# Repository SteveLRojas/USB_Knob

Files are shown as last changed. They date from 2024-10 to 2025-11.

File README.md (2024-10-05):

# USB_Knob
A USB knob that can scroll, pan, adjust the volume, and more. Uses the CH552 USB microcontroller.

## What does it do?
This device is a computer peripheral, it can scroll, pan (scroll horizontally), and adjust the volume. It also has simple media controls such as play/pause, next, and prev.  

## How does it work?
The device has 3 buttons: left, center, and right. These 3 buttons are used to set the "mode" of the device, and when they are held down they act as function modifiers. The device also has a knob which has a fourth button, and is the most frequently used control on the device. Three indicator LEDs indicate the current "mode" setting of the device.  

## Device features
### Scroll mode
- Press the left button to enter scroll mode.  
- The knob button functions as the middle mouse button.  
- While the left button is released spinning the knob scrolls vertically (like a mouse wheel).  
- While the left button is pressed spinning the knob adjusts the scrolling speed (the speed range is 1 to 10).  
### Pan mode
- Press the center button to enter pan mode.  
- If the mouse wiggler feature is enabled (option set at compile time) the knob button toggles the mouse wiggler on/off. The mouse wiggler only acts when the knob is in pan mode, but the on/off state is maintained even when the device is in a different mode.  
- If the mouse wiggler feature is not enabled then the knob button functions as the middle mouse button.  
- While the center button is released spinning the knob scrolls horizontally.  
- While the center button is pressed spinning the knob adjusts the scrolling (pan) speed (the range is 1 to 10).  
### Volume mode
- Press the right button to enter volume mode.  
- While the right button is released the knob button acts as a mute button.  
- While the right button is pressed the knob button acts as a play/pause button.  
- While the right button is released spinning the knob adjusts the volume.  
- While the right button is pressed spinning the knob functions as media next/prev buttons.

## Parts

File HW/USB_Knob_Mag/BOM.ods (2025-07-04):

Part | #Needed | #Owned | Satisfied? | Location
CH552T | 1 | 6 | TRUE | Project box
AS5600-ASOM | 1 | 20 | TRUE | Project box
Crystal 24MHz 3225 | 1 | 0 | FALSE | Crystal Box
LED Orange 0805 | 3 | 1000 | TRUE | Project box
USB C Socket | 1 | 10 | TRUE | Connector box
Pin Header 1X3 right angle | 1 | 10 | TRUE | Connector box
Pin Header 1X2 right angle | 1 | 10 | TRUE | Connector box
Capacitor 1u 0805 | 1 | 200 | TRUE | Box 7
Capacitor 0.1u 0805 | 3 | 100 | TRUE | Project box
Capacitor 10u 1206 | 1 | 50 | TRUE | Project box
Capacitor 20p 0805 | 2 | 0 | FALSE
Push Button SMD | 3 | 20 | TRUE | Project box
Resistor 5.1K 0805 | 2 | 1000 | TRUE | Project box
Resistor 1K 0805 | 8 | 1000 | TRUE | Box 8
Resistor 10K 0805 | 1 | 1000 | TRUE | Box 8

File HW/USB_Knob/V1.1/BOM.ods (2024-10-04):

Part | #Needed | #Owned | Satisfied? | Location
CH552T | 1 | 12 | TRUE | Project box
74LVC1G17 | 2 | 14 | TRUE | Project box
Crystal 24MHz 3225 | 1 | 0 | FALSE
LED Orange 0805 | 3 | 1000 | TRUE | Project box
USB Mini C Socket | 1 | 10 | TRUE | Connector box
Rotary Encoder | 1 | 10 | TRUE | Project box
Pin Header 1X3 | 1 | 10 | TRUE | Connector box
Pin Header 1X2 | 1 | 10 | TRUE | Connector box
Capacitor 0.01u 0805 | 2 | 100 | TRUE | Project box
Capacitor 0.1u 0805 | 4 | 100 | TRUE | Project box
Capacitor 10u 1206 | 1 | 10 | TRUE | Project box
Capacitor 20p 0805 | 2 | 0 | FALSE
Push Button SMD | 3 | 50 | TRUE | Project box
Resistor 5.1K 0805 | 2 | 1000 | TRUE | Project box
Resistor 1K 0805 | 9 | 1000 | TRUE | Box 8
Resistor 10K 0805 | 3 | 1000 | TRUE | Box 8

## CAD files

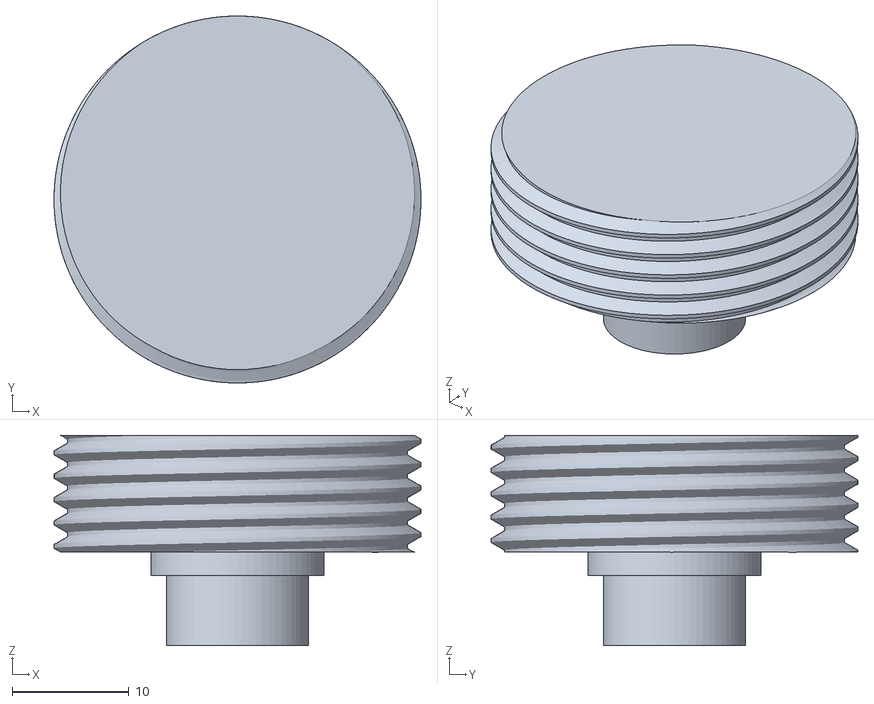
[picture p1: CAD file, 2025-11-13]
3d_models/mag/USB_Knob_Mag_Holder.stl
31.4 x 31.4 x 18.0

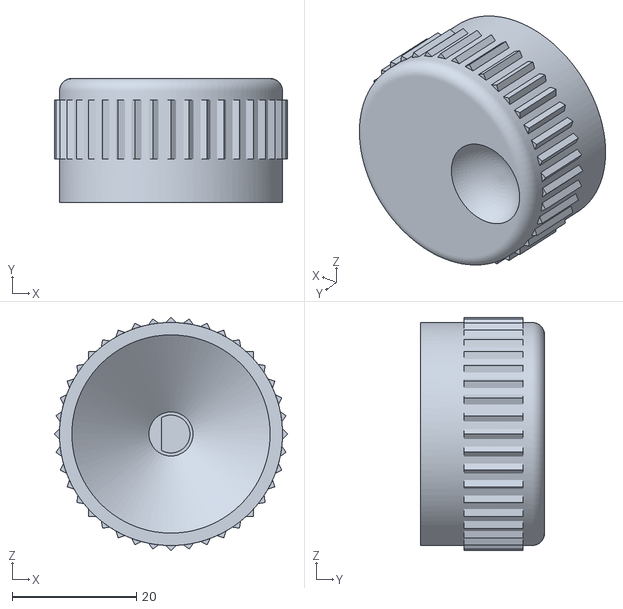
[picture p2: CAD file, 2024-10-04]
3d_models/USB_knob_the_v1.1.stl
37.5 x 20.0 x 37.5

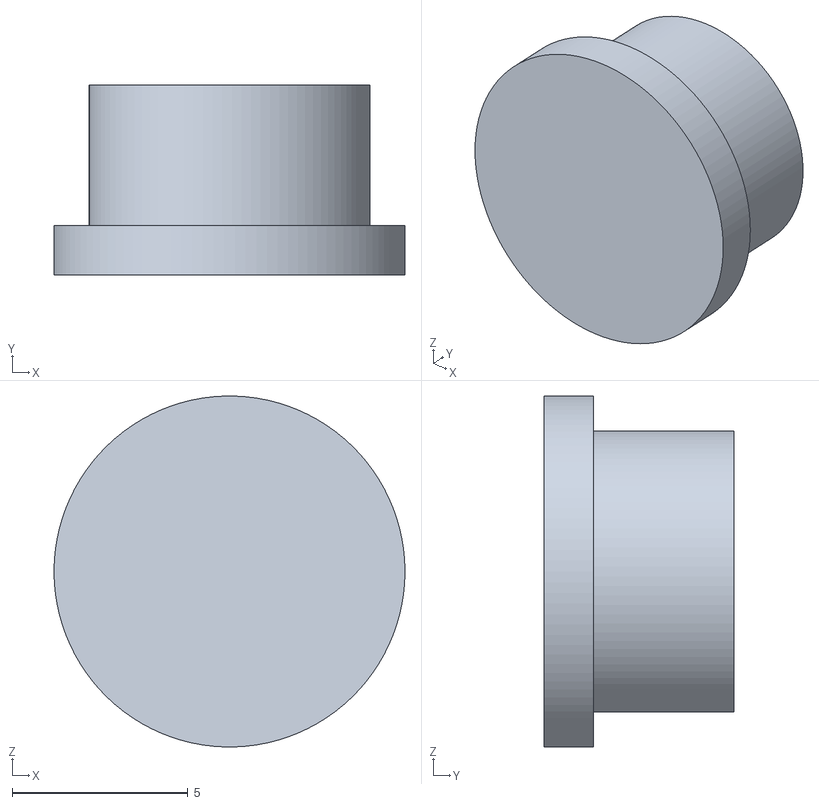
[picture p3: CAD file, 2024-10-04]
3d_models/knob_button_v1.1.stl
10.0 x 5.40 x 10.00

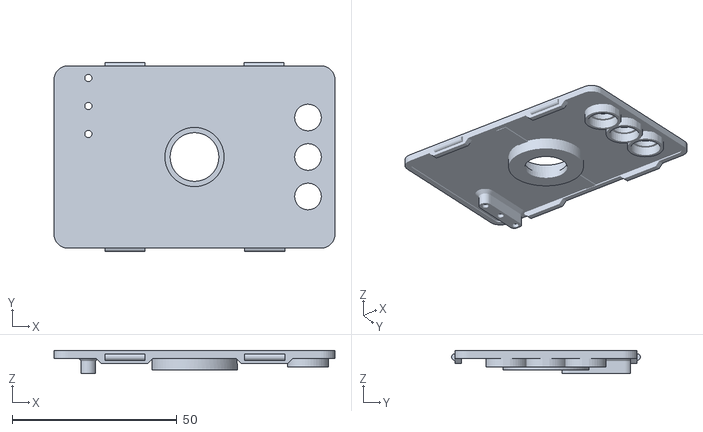
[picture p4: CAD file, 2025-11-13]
3d_models/mag/USB_Knob_Cap_Mag.stl
85.4 x 57.4 x 7.00

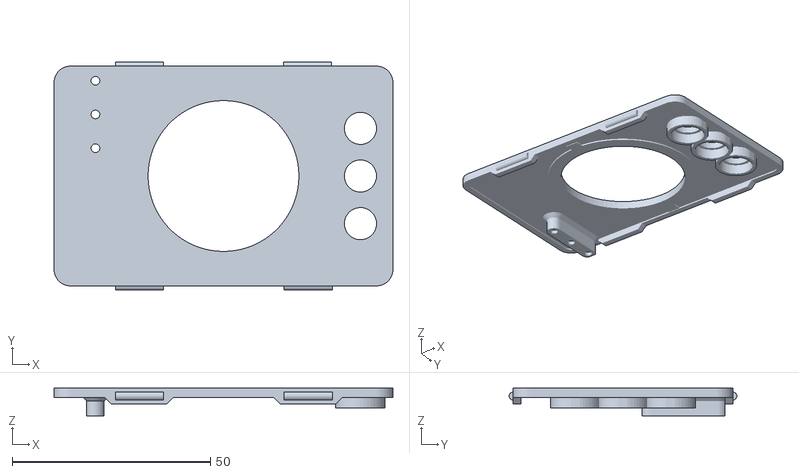
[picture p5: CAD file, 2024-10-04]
3d_models/knob_cap.stl
85.4 x 57.4 x 7.00

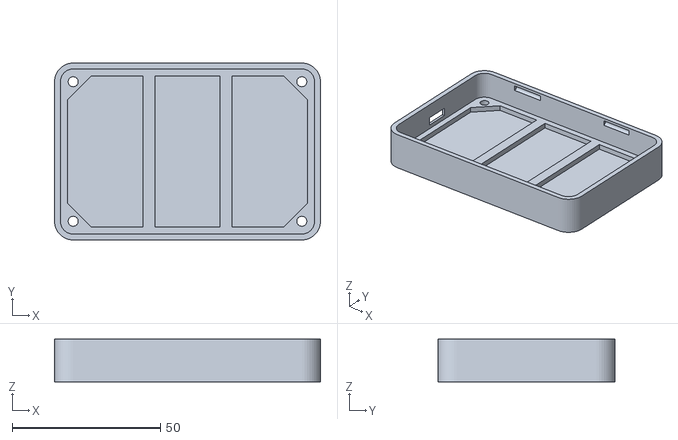
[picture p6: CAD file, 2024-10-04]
3d_models/knob_box.stl
89.6 x 59.6 x 14.4

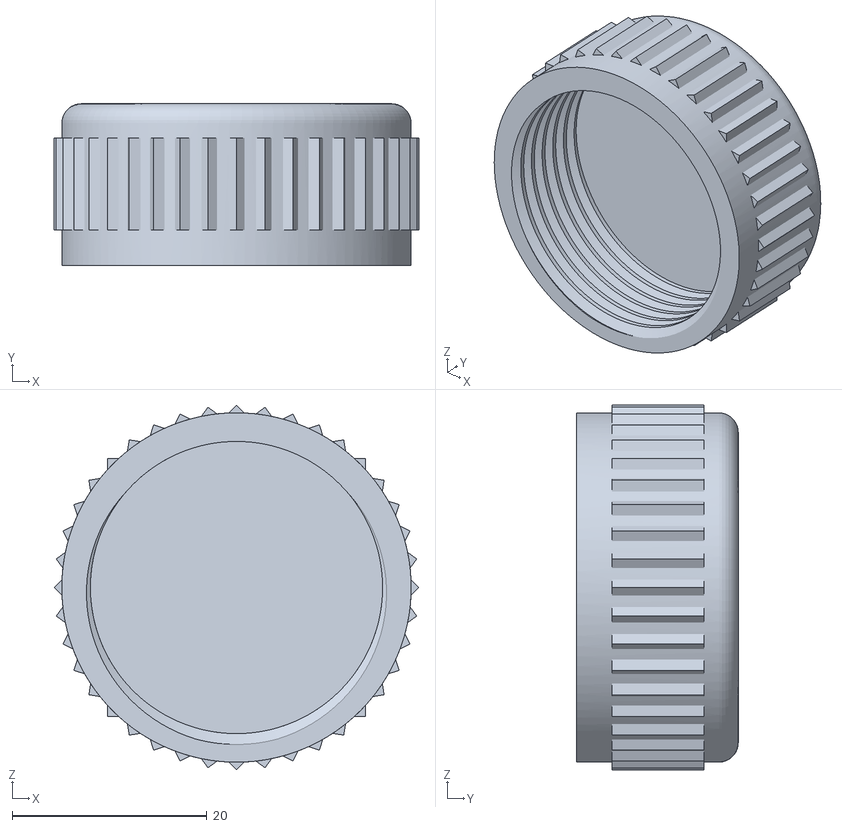
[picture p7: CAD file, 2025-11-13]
3d_models/mag/USB_Knob_Mag_Screw.stl
37.5 x 16.6 x 37.5

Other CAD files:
3d_models/USB_Knob_Box v5.f3d
3d_models/USB_knob_the v4.f3d
3d_models/button v2.f3d
3d_models/mag/USB_Knob_Box_Mag v5.f3d
3d_models/mag/USB_Knob_Mag_Holder v4.f3d
3d_models/mag/USB_Knob_Mag_screw v3.f3d

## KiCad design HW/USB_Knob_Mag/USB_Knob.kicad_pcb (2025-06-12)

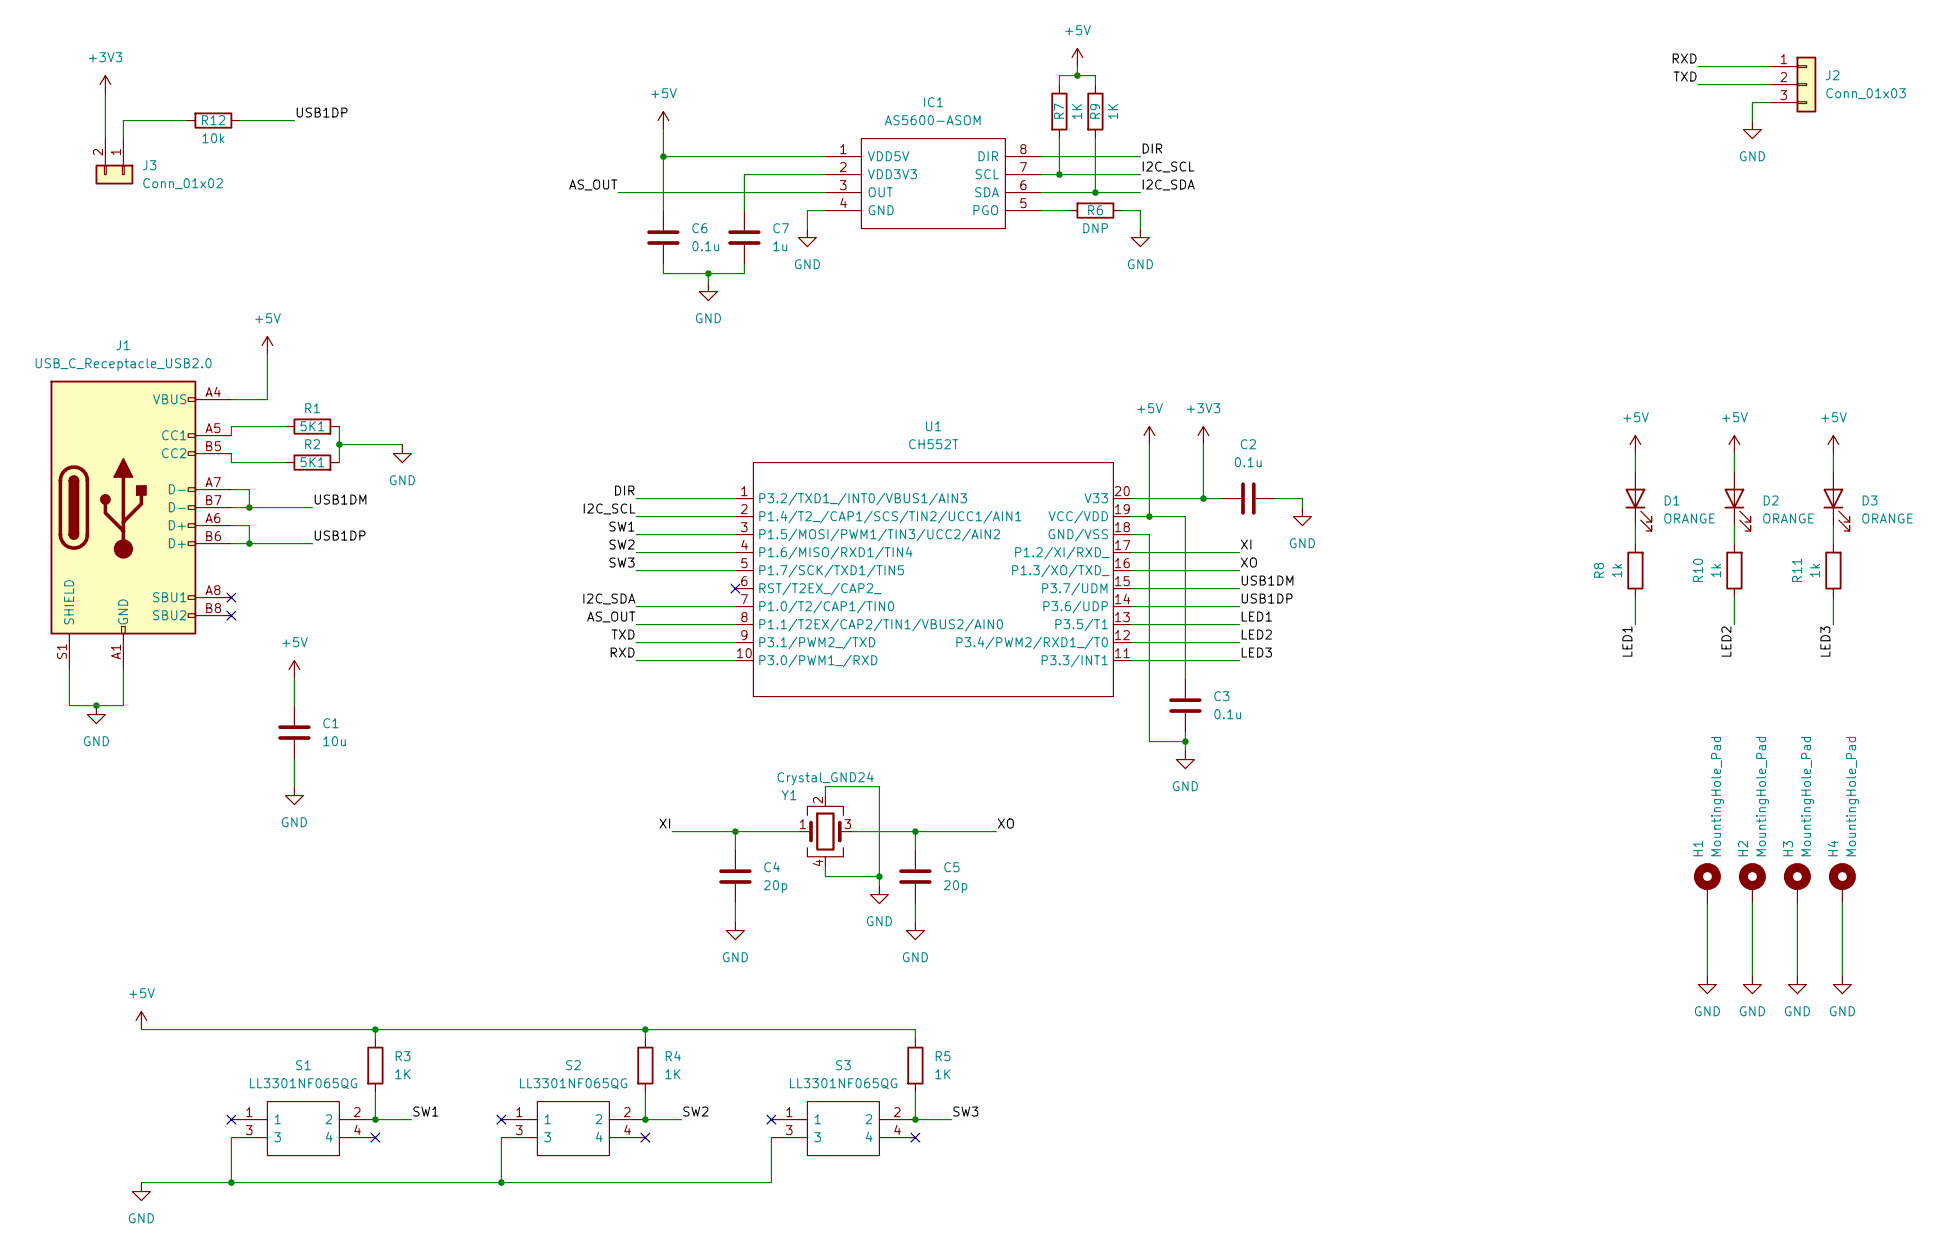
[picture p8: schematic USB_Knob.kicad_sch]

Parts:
C1: 10u; C_1206_3216Metric
C2, C3, C6: 0.1u; C_0805_2012Metric
C4, C5: 20p; C_0805_2012Metric
C7: 1u; C_0805_2012Metric
D1, D2, D3: ORANGE; LED_0805_2012Metric
H1, H2, H3, H4: MountingHole_Pad; MountingHole_3.2mm_M3_Pad
IC1: AS5600-ASOM; SOIC127P600X175-8N; Mouser Part Number 985-AS5600-ASOM
J1: USB_C_Receptacle_USB2.0; USB_C_Receptacle_HRO_TYPE-C-31-M-12
J2: Conn_01x03; PinHeader_1x03_P2.54mm_Horizontal
J3: Conn_01x02; PinHeader_1x02_P2.54mm_Horizontal
R1, R2: 5K1; R_0805_2012Metric
R3, R4, R5, R7, R9: 1K; R_0805_2012Metric
R6: DNP; R_0805_2012Metric
R8, R10, R11: 1k; R_0805_2012Metric
R12: 10k; R_0805_2012Metric
S1, S2, S3: LL3301NF065QG; Mouser Part Number 612-LL3301NF065QG
U1: CH552T; TSSOP-20_4.4x6.5mm_P0.65mm
Y1: Crystal_GND24; Crystal_SMD_3225-4Pin_3.2x2.5mm

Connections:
+3V3: C2.1, J3.2, U1.20 (V33)
+5V: C1.1, C3.2, C6.2, D1.2 (A), D2.2 (A), D3.2 (A), IC1.1 (VDD5V), J1.A4 (VBUS), J1.A9 (VBUS), J1.B4 (VBUS), J1.B9 (VBUS), R3.1, R4.1, R5.1, R7.1, R9.1, U1.19 (VCC/VDD)
/AS_OUT: IC1.3 (OUT), U1.8 (P1.1/T2EX/CAP2/TIN1/VBUS2/AIN0)
/DIR: IC1.8 (DIR), U1.1 (P3.2/TXD1_/INT0/VBUS1/AIN3)
/I2C_SCL: IC1.7 (SCL), R7.2, U1.2 (P1.4/T2_/CAP1/SCS/TIN2/UCC1/AIN1)
/I2C_SDA: IC1.6 (SDA), R9.2, U1.7 (P1.0/T2/CAP1/TIN0)
/LED1: R8.1, U1.13 (P3.5/T1)
/LED2: R10.1, U1.12 (P3.4/PWM2/RXD1_/T0)
/LED3: R11.1, U1.11 (P3.3/INT1)
/RXD: J2.1, U1.10 (P3.0/PWM1_/RXD)
/SW1: R3.2, S1.2, U1.3 (P1.5/MOSI/PWM1/TIN3/UCC2/AIN2)
/SW2: R4.2, S2.2, U1.4 (P1.6/MISO/RXD1/TIN4)
/SW3: R5.2, S3.2, U1.5 (P1.7/SCK/TXD1/TIN5)
/TXD: J2.2, U1.9 (P3.1/PWM2_/TXD)
/USB1DM: J1.A7 (D-), J1.B7 (D-), U1.15 (P3.7/UDM)
/USB1DP: J1.A6 (D+), J1.B6 (D+), R12.1, U1.14 (P3.6/UDP)
/XI: C4.2, U1.17 (P1.2/XI/RXD_), Y1.1
/XO: C5.2, U1.16 (P1.3/XO/TXD_), Y1.3
GND: C1.2, C2.2, C3.1, C4.1, C5.1, C6.1, C7.1, H1.1, H2.1, H3.1, H4.1, IC1.4 (GND), J1.A1 (GND), J1.A12 (GND), J1.B1 (GND), J1.B12 (GND), J1.S1 (SHIELD), J2.3, R1.2, R2.2, R6.1, S1.3, S2.3, S3.3, U1.18 (GND/VSS), Y1.2, Y1.4
unnamed: C7.2, IC1.2 (VDD3V3)
unnamed: D1.1 (K), R8.2
unnamed: D2.1 (K), R10.2
unnamed: D3.1 (K), R11.2
unnamed: IC1.5 (PGO), R6.2
unnamed: J1.A5 (CC1), R1.1
unnamed: J1.B5 (CC2), R2.1
unnamed: J3.1, R12.2

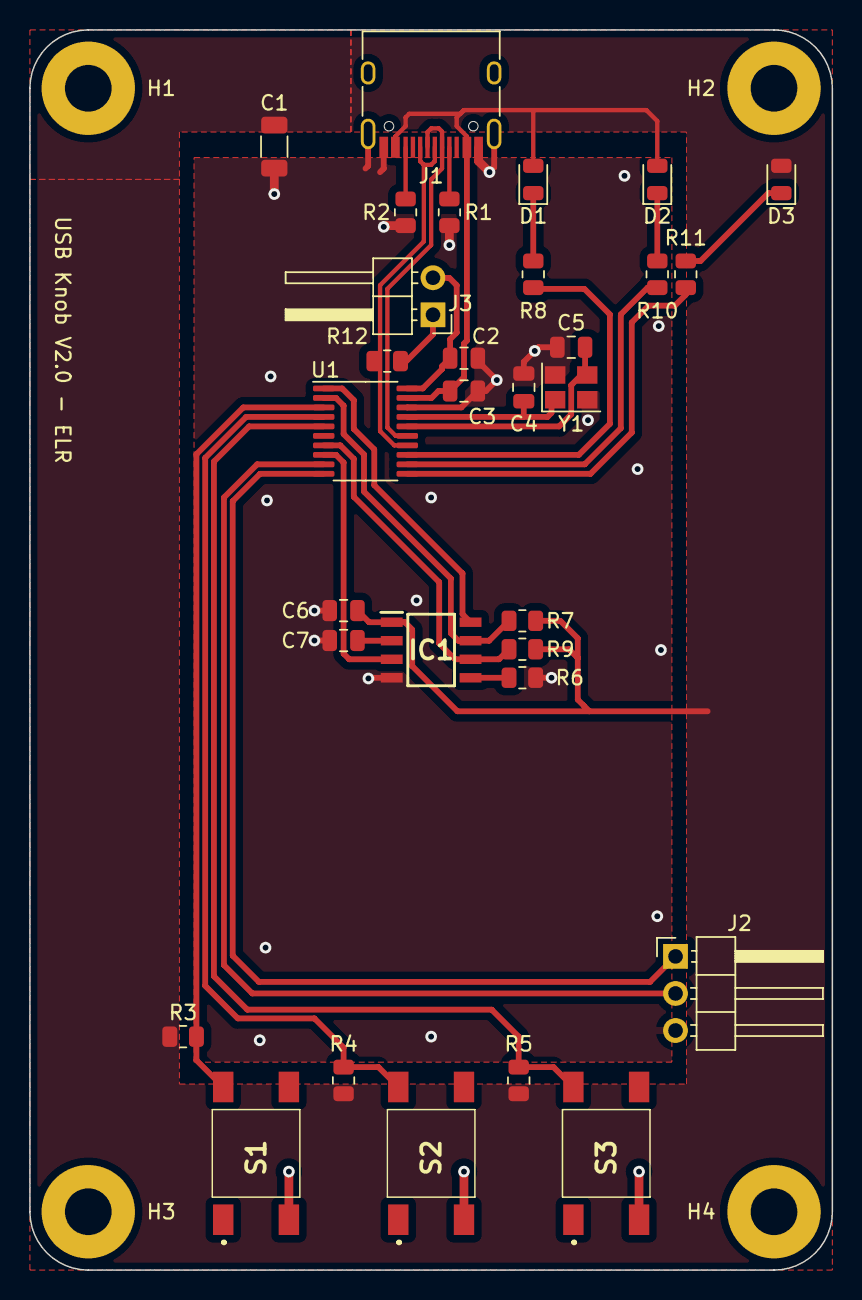
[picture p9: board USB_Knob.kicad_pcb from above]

Board: 2 copper layers, 55.0 x 85.0 mm, 35 parts (0 on the bottom side), 27 nets.

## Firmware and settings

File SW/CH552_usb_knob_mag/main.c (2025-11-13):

#include "CH552.H"
#include "CH552_RCC.h"
#include "CH552_GPIO.h"
#include "CH552_UART.h"
#include "CH552_TIMER.h"
#include "CH552_HID_CC_PAN_MOUSE.h"
#include "CH552_I2C.h"
#include "CH552_AS5600.h"
#include "pseudo_random.h"

#define BAUD_RATE		125000ul
#define ENABLE_DEBUG	0
#define ENABLE_WIGGLER	1
#define SPEED_STEPS		16
#define FINE_SHIFT		7
#define COARSE_HYSTERESIS	128
#define FINE_HYSTERESIS		4
#define DEBOUNCE_SAMPLES	8

//Pins:
// I2C_SDA = P10
// AS_OUT = P11
// I2C_SCL = P14
// SW1 = P15
// SW2 = P16
// SW3 = P17
// RXD = P30
// TXD = P31
// DIR = P32
// LED3 = P33
// LED2 = P34
// LED1 = P35
// UDP = P36
// UDM = P37

#define KNOB_MODE_SCROLL 0
#define KNOB_MODE_PAN 1
#define KNOB_MODE_VOLUME 2

#if ENABLE_DEBUG
char code test_string[] = "Unicorn\n";
char code pos_raw_str[] = "knob_pos_raw: ";
char code pos_coarse_str[] = "knob_pos_coarse: ";
char code pos_fine_str[] = "knob_pos_fine: ";
char code pos_change_str[] = "knob_pos_change: ";
char code str_bad_command[] = "Bad command!\n";
char hex_str[6];
UINT8 datagram[2];
UINT8 temp;
UINT8 count;
UINT16 as_read;
UINT8 reporting_enabled = 0;
#endif

//Timers
volatile UINT16 mouse_timer = 0;
volatile UINT16 cc_timer = 0;
volatile UINT8 mouse_timeout = 0;
volatile UINT8 cc_timeout = 0;

//Knob state
UINT8 knob_mode = KNOB_MODE_SCROLL;
UINT8 knob_mode_prev = KNOB_MODE_SCROLL;
signed char scroll_speed = SPEED_STEPS / 2;
signed char pan_speed = SPEED_STEPS / 2;

#if ENABLE_WIGGLER
//Wiggler state
UINT8 wiggler_active = 0;
volatile UINT8 wiggler_update_vel = 0;
volatile UINT8 wiggler_update_pos = 0;
volatile UINT8 wiggler_update_times = 0;
UINT8 time = 0;
UINT16 run_time = 0;
UINT16 stop_time = 0;
signed char x_velocity;
signed char y_velocity;
signed short x_position;
signed short y_position;
signed short prev_x_position;
signed short prev_y_position;
signed char x_delta;
signed char y_delta;
#endif

void on_timer(void)
{
	++mouse_timer;
	++cc_timer;
	
	if(hid_mouse_idle_rate && ((UINT8)(mouse_timer >> 2) >= hid_mouse_idle_rate))
	{
		mouse_timeout = 1;
		mouse_timer = 0;
	}
	
	if(hid_cc_idle_rate && ((UINT8)(cc_timer >> 2) >= hid_cc_idle_rate))
	{
		cc_timeout = 1;
		cc_timer = 0;
	}

#if ENABLE_WIGGLER
	if((knob_mode != KNOB_MODE_VOLUME) && wiggler_active)
	{
		if(run_time)
		{
			if(time == 0x00)
			{
				wiggler_update_vel = 1;
			}
			if((time & 0x07) == 0x00)
			{
				wiggler_update_pos = 1;
			}
			--run_time;
		}
		else if(stop_time)
		{
			--stop_time;
		}
		else
		{
			wiggler_update_times = 1;
		}
		++time;
	}
#endif
}

#if ENABLE_DEBUG
char code hex_table[16] = {0x30, 0x31, 0x32, 0x33, 0x34, 0x35, 0x36, 0x37, 0x38, 0x39, 0x41, 0x42, 0x43, 0x44, 0x45, 0x46};
void byte_to_hex(UINT8 value, char* buff)
{
	buff[0] = hex_table[(value >> 4) & 0x0F];
	buff[1] = hex_table[(value) & 0x0F];
	buff[2] = '\0';
}
#endif

int main()
{
	UINT8 sw1_state;
	UINT8 sw2_state;
	UINT8 sw3_state;
	UINT8 sw1_count;
	UINT8 sw2_count;
	UINT8 sw3_count;
	UINT8 sw1_press_event;
	UINT8 sw2_press_event;
	UINT8 sw3_press_event;
	UINT8 sw1_release_event;
	UINT8 sw2_release_event;
	UINT8 sw3_release_event;
	
	signed short knob_pos_raw;
	signed short knob_pos_coarse;
	signed short knob_pos_fine;
	signed short knob_pos_change;
	UINT8 knob_inc_event;
	UINT8 knob_dec_event;
	
	signed short pos_accum;
	signed short pos_accum_prev;
	
	rcc_set_clk_freq(RCC_CLK_FREQ_24M);
	
	gpio_set_mode(GPIO_MODE_INPUT, GPIO_PORT_1, GPIO_PIN_1 | GPIO_PIN_5 | GPIO_PIN_6 | GPIO_PIN_7);	//AS_OUT, SW1, SW2, SW3
	gpio_set_mode(GPIO_MODE_OD, GPIO_PORT_1, GPIO_PIN_0 | GPIO_PIN_4);	//I2C_SDA, I2C_SCL
	gpio_set_mode(GPIO_MODE_PP, GPIO_PORT_3, GPIO_PIN_1 | GPIO_PIN_2 | GPIO_PIN_3 | GPIO_PIN_4 | GPIO_PIN_5);	//TXD, DIR, LED3, LED2, LED1
	gpio_set_mode(GPIO_MODE_INPUT, GPIO_PORT_3, GPIO_PIN_0);	//RXD
	gpio_clear_pin(GPIO_PORT_3, GPIO_PIN_2);	//Drive DIR low
	
	i2c_init(GPIO_PORT_1, GPIO_PIN_0, GPIO_PORT_1, GPIO_PIN_4);
	
#if ENABLE_DEBUG
	uart0_init(TIMER_1, BAUD_RATE, UART_0_P30_P31);
	timer_init(TIMER_0, NULL);
	timer_set_period(TIMER_0, FREQ_SYS / 1000ul);	//period is 1ms
#endif
	
	timer_init(TIMER_2, on_timer);
	timer_set_period(TIMER_2, FREQ_SYS / 1000ul);	//period is 1ms
	timer_start(TIMER_2);
	EA = 1;	//enable interupts
	E_DIS = 0;
	
	if(rcc_get_rst_typ() == RCC_RST_TYP_WDOG)
	{
		rcc_delay_ms(500);
	}
	
#if ENABLE_DEBUG
	//Blink LED once
	gpio_clear_pin(GPIO_PORT_3, GPIO_PIN_3 | GPIO_PIN_4 | GPIO_PIN_5);
	timer_long_delay(TIMER_0, 250);
	gpio_set_pin(GPIO_PORT_3, GPIO_PIN_3 | GPIO_PIN_4 | GPIO_PIN_5);
	timer_long_delay(TIMER_0, 250);
	uart_write_string(UART_0, test_string);
	
	byte_to_hex(RESET_KEEP, hex_str);
	hex_str[2] = '\n';
	hex_str[3] = '\0';
	uart_write_string(UART_0, hex_str);
#endif
	
	hid_init();
	pseudo_random_seed(0xDEADBEEF);
	rcc_reload_wdog(0x00);
	rcc_set_wdog_rst_en(RCC_WDOG_ENABLED);
	
	gpio_clear_pin(GPIO_PORT_3, GPIO_PIN_5);	//turn on LED1
	sw1_state = gpio_read_pin(GPIO_PORT_1, GPIO_PIN_5);
	sw2_state = gpio_read_pin(GPIO_PORT_1, GPIO_PIN_6);
	sw3_state = gpio_read_pin(GPIO_PORT_1, GPIO_PIN_7);
	sw1_count = 0;
	sw2_count = 0;
	sw3_count = 0;
	knob_pos_coarse = as5600_read_word(AS_REG_RAW_ANGLE) << 4;
	knob_pos_fine = knob_pos_coarse;
	pos_accum = 0;
	pos_accum_prev = 0;
	while(TRUE)
	{
		//Debounce buttons
		if(gpio_read_pin(GPIO_PORT_1, GPIO_PIN_5))
			sw1_count += (sw1_count < DEBOUNCE_SAMPLES);
		else
			sw1_count -= (sw1_count != 0);
		
		if(gpio_read_pin(GPIO_PORT_1, GPIO_PIN_6))
			sw2_count += (sw2_count < DEBOUNCE_SAMPLES);
		else
			sw2_count -= (sw2_count != 0);
		
		if(gpio_read_pin(GPIO_PORT_1, GPIO_PIN_7))
			sw3_count += (sw3_count < DEBOUNCE_SAMPLES);
		else
			sw3_count -= (sw3_count != 0);
		
		sw1_press_event = (sw1_state && !sw1_count);
		sw2_press_event = (sw2_state && !sw2_count);
		sw3_press_event = (sw3_state && !sw3_count);
		
		sw1_release_event = (!sw1_state && (sw1_count == DEBOUNCE_SAMPLES));
		sw2_release_event = (!sw2_state && (sw2_count == DEBOUNCE_SAMPLES));
		sw3_release_event = (!sw3_state && (sw3_count == DEBOUNCE_SAMPLES));
		
		sw1_state = (sw1_state && sw1_count) || (sw1_count == DEBOUNCE_SAMPLES);
		sw2_state = (sw2_state && sw2_count) || (sw2_count == DEBOUNCE_SAMPLES);
		sw3_state = (sw3_state && sw3_count) || (sw3_count == DEBOUNCE_SAMPLES);
			
		//Update encoder position and events
		knob_pos_raw = as5600_read_word(AS_REG_RAW_ANGLE) << 4;
		knob_pos_change = knob_pos_raw - knob_pos_coarse;
		if((knob_pos_change < -(signed short)(COARSE_HYSTERESIS << 4)) || (knob_pos_change > (signed short)(COARSE_HYSTERESIS << 4)))
		{
			knob_inc_event = (knob_pos_change > 0);
			knob_dec_event = (knob_pos_change < 0);
			knob_pos_coarse = knob_pos_raw;
		}
		else
		{
			knob_inc_event = 0;
			knob_dec_event = 0;
		}
		
		knob_pos_change = (knob_pos_raw - knob_pos_fine) >> 4;	//HINT: Behavior of right shift on a signed operand is compiler specific... The intent is dividing by 16.
		if((knob_pos_change < -(signed short)FINE_HYSTERESIS) || (knob_pos_change > (signed short)FINE_HYSTERESIS))
			knob_pos_fine = knob_pos_raw;
		else
			knob_pos_change = 0;
		
#if ENABLE_DEBUG		
		//debug prints
		if(knob_inc_event | knob_dec_event)
		{
			//print knob_pos_raw
			uart_write_string(UART_0, pos_raw_str);
			byte_to_hex((UINT8)(knob_pos_raw >> 8), hex_str);
			byte_to_hex((UINT8)(knob_pos_raw), hex_str + 2);
			hex_str[4] = '\n';
			hex_str[5] = '\0';
			uart_write_string(UART_0, hex_str);
			
			//print knob_pos_coarse
			uart_write_string(UART_0, pos_coarse_str);
			byte_to_hex((UINT8)(knob_pos_coarse >> 8), hex_str);
			byte_to_hex((UINT8)(knob_pos_coarse), hex_str + 2);
			hex_str[4] = '\n';
			hex_str[5] = '\0';
			uart_write_string(UART_0, hex_str);
			
			//print knob_pos_fine
			uart_write_string(UART_0, pos_fine_str);
			byte_to_hex((UINT8)(knob_pos_fine >> 8), hex_str);
			byte_to_hex((UINT8)(knob_pos_fine), hex_str + 2);
			hex_str[4] = '\n';
			hex_str[5] = '\0';
			uart_write_string(UART_0, hex_str);
			
			//print knob_pos_change
			uart_write_string(UART_0, pos_change_str);
			byte_to_hex((UINT8)(knob_pos_change >> 8), hex_str);
			byte_to_hex((UINT8)(knob_pos_change), hex_str + 2);
			hex_str[4] = '\n';
			hex_str[5] = '\0';
			uart_write_string(UART_0, hex_str);
		}
#endif
		
		//Update knob_mode and LEDs
		if(sw2_state)	//change the mode only while sw2 is not pressed
		{
			if(sw1_press_event)
				knob_mode -= 1;
			if(sw3_press_event)
				knob_mode += 1;
			
			if(knob_mode & 0x80)	//if knob_mode is "negative"
				knob_mode = KNOB_MODE_VOLUME;
			else if(knob_mode > KNOB_MODE_VOLUME)
				knob_mode = KNOB_MODE_SCROLL;
			
			if(knob_mode != knob_mode_prev)
			{
				gpio_set_pin(GPIO_PORT_3, GPIO_PIN_3 | GPIO_PIN_4 | GPIO_PIN_5);
				gpio_clear_pin(GPIO_PORT_3, GPIO_PIN_5 >> knob_mode);
				knob_mode_prev = knob_mode;
			}
		}
		
		//Handle knob and button events
		switch(knob_mode)
		{
			case KNOB_MODE_SCROLL:
				if(sw2_state)
				{
					if(knob_pos_change)
					{
						pos_accum += knob_pos_change * scroll_speed;
						knob_pos_change = (pos_accum_prev >> FINE_SHIFT) - (pos_accum >> FINE_SHIFT);
						pos_accum_prev = pos_accum;
						hid_mouse_scroll((signed char)knob_pos_change, 0);
					}
				}
				else
				{
#if ENABLE_WIGGLER
					if(sw3_press_event)
					{
						wiggler_active = !wiggler_active;
						stop_time = 0;	//start moving immediately when activated
					}
					if(sw1_press_event)
						hid_mouse_press(HID_MOUSE_BTN_WHEEL);
#else
					if(sw1_press_event | sw3_press_event)
						hid_mouse_press(HID_MOUSE_BTN_WHEEL);
#endif
					if(knob_inc_event)
						++scroll_speed;
					if(knob_dec_event)
						--scroll_speed;
					if(scroll_speed < 1)
						scroll_speed = 1;
					if(scroll_speed > (UINT8)SPEED_STEPS)
						scroll_speed = (UINT8)SPEED_STEPS;
				}
				if(sw1_release_event | sw3_release_event)	//Make sure to release the mouse button even if sw2 is released first.
					hid_mouse_release(HID_MOUSE_BTN_WHEEL);
				break;
			case KNOB_MODE_PAN:
				if(sw2_state)
				{
					if(knob_pos_change)
					{
						pos_accum += knob_pos_change * pan_speed;
						knob_pos_change = (pos_accum >> FINE_SHIFT) - (pos_accum_prev >> FINE_SHIFT);
						pos_accum_prev = pos_accum;
						hid_mouse_scroll(0, (signed char)knob_pos_change);
					}
				}
				else
				{
#if ENABLE_WIGGLER
					if(sw3_press_event)
					{
						wiggler_active = !wiggler_active;
						stop_time = 0;	//start moving immediately when activated
					}
					if(sw1_press_event)
						hid_mouse_press(HID_MOUSE_BTN_WHEEL);
#else
					if(sw1_press_event | sw3_press_event)
						hid_mouse_press(HID_MOUSE_BTN_WHEEL);
#endif
					if(knob_inc_event)
						++pan_speed;
					if(knob_dec_event)
						--pan_speed;
					if(pan_speed < 1)
						pan_speed = 1;
					if(pan_speed > (UINT8)SPEED_STEPS)
						pan_speed = (UINT8)SPEED_STEPS;
				}
				if(sw1_release_event | sw3_release_event)	//Make sure to release the mouse button even if sw2 is released first.
					hid_mouse_release(HID_MOUSE_BTN_WHEEL);
				break;
			case KNOB_MODE_VOLUME:
				if(sw2_state)
				{
					if(knob_inc_event)
					{
						hid_cc_press(HID_CC_BTN_VOL_UP);
						while(hid_cc_report_pending);
						hid_cc_press(HID_CC_BTN_NONE);
					}
					if(knob_dec_event)
					{
						hid_cc_press(HID_CC_BTN_VOL_DOWN);
						while(hid_cc_report_pending);
						hid_cc_press(HID_CC_BTN_NONE);
					}
				}
				else
				{
					if(knob_inc_event)
					{
						hid_cc_press(HID_CC_BTN_MEDIA_NEXT);
						while(hid_cc_report_pending);
						hid_cc_press(HID_CC_BTN_NONE);
					}
					if(knob_dec_event)
					{
						hid_cc_press(HID_CC_BTN_MEDIA_PREV);
						while(hid_cc_report_pending);
						hid_cc_press(HID_CC_BTN_NONE);
					}
					
					if(sw1_press_event)
						hid_cc_press(HID_CC_BTN_VOL_MUTE);
					if(sw3_press_event)
						hid_cc_press(HID_CC_BTN_PLAY_PAUSE);
				}
				if(sw1_release_event | sw3_release_event)
					hid_cc_press(HID_CC_BTN_NONE);
				break;
			default:
				break;
		}
		
#if ENABLE_WIGGLER
		if(wiggler_update_vel)
		{
			pseudo_random_generate(16);
			x_velocity = pseudo_random_get_byte();
			y_velocity = pseudo_random_get_word() >> 8;
			if(x_velocity & 0x80)
				++x_velocity;
			if(y_velocity & 0x80)
				++y_velocity;
			wiggler_update_vel = 0;
		}

		if(wiggler_update_pos)
		{
			x_position += x_velocity;
			y_position += y_velocity;
			x_delta = (signed char)((x_position >> 4) - (prev_x_position >> 4));
			y_delta = (signed char)((y_position >> 4) - (prev_y_position >> 4));
			prev_x_position = x_position;
			prev_y_position = y_position;
			hid_mouse_move(x_delta, y_delta);
			wiggler_update_pos = 0;
		}
		
		if(wiggler_update_times)
		{
			pseudo_random_generate(16);
			run_time = pseudo_random_get_word();
			pseudo_random_generate(16);
			stop_time = pseudo_random_get_word();
			
			run_time = run_time >> 2;
			stop_time = stop_time >> 2;
			run_time += 1000;
			stop_time += 1000;
			wiggler_update_times = 0;
		}
#endif
		
		if(mouse_timeout)
		{
			hid_mouse_send_report();
			mouse_timeout = 0;
		}
		
		if(cc_timeout)
		{
			hid_cc_send_report();
			cc_timeout = 0;
		}
#if ENABLE_DEBUG
		if(uart_bytes_available(UART_0) >= 2)
		{
			temp = uart_peek(UART_0);
			if((temp == '\r') || (temp == '\n'))
			{
				(void)uart_read_byte(UART_0);
				continue;
			}
			
			uart_read_bytes(UART_0, datagram, 2);
			for(count = 0; count < 2; ++count)
			{
				temp = datagram[count];
				if(temp >= '0' && temp <= '9')  //convert numbers
					temp = temp - '0';
				else if(temp >= 'A' && temp <= 'F')   //convert uppercase letters
					temp = temp - 'A' + 10;
				else if(temp >= 'a' && temp <= 'f')   //convert the annoying lowercase letters
					temp = temp - 'a' + 10;
				else
					continue;

				RESET_KEEP = RESET_KEEP << 4;
				RESET_KEEP = RESET_KEEP | temp;
			}
			
			switch(RESET_KEEP)
			{
				case 0x00:
					as_read = as5600_read_word(AS_REG_CONF);
					byte_to_hex((UINT8)(as_read >> 8), hex_str);
					byte_to_hex((UINT8)as_read, hex_str + 2);
					hex_str[4] = '\n';
					hex_str[5] = '\0';
					uart_write_string(UART_0, hex_str);
					break;
				case 0x01:
					as_read = as5600_read_word(AS_REG_RAW_ANGLE);
					byte_to_hex((UINT8)(as_read >> 8), hex_str);
					byte_to_hex((UINT8)as_read, hex_str + 2);
					hex_str[4] = '\n';
					hex_str[5] = '\0';
					uart_write_string(UART_0, hex_str);
					break;
				case 0x02:
					as_read = as5600_read_word(AS_REG_ANGLE);
					byte_to_hex((UINT8)(as_read >> 8), hex_str);
					byte_to_hex((UINT8)as_read, hex_str + 2);
					hex_str[4] = '\n';
					hex_str[5] = '\0';
					uart_write_string(UART_0, hex_str);
					break;
				case 0x03:
					temp = as5600_read_byte(AS_REG_STATUS);
					byte_to_hex(temp, hex_str);
					hex_str[2] = '\n';
					hex_str[3] = '\0';
					uart_write_string(UART_0, hex_str);
					break;
				case 0x04:
					temp = as5600_read_byte(AS_REG_AGC);
					byte_to_hex(temp, hex_str);
					hex_str[2] = '\n';
					hex_str[3] = '\0';
					uart_write_string(UART_0, hex_str);
					break;
				case 0x05:
					as_read = as5600_read_word(AS_REG_MAGNITUDE);
					byte_to_hex((UINT8)(as_read >> 8), hex_str);
					byte_to_hex((UINT8)as_read, hex_str + 2);
					hex_str[4] = '\n';
					hex_str[5] = '\0';
					uart_write_string(UART_0, hex_str);
					break;
				case 0x06:
					reporting_enabled = 1;
					break;
				case 0x07:
					reporting_enabled = 0;
					break;
				default:
					uart_write_string(UART_0, str_bad_command);
					break;
			}
		}
		
		if(reporting_enabled && (timer_overflow_counts[TIMER_2] >= 200))
		{
			timer_overflow_counts[TIMER_2] = 0;
			as_read = as5600_read_word(AS_REG_RAW_ANGLE);
			byte_to_hex((UINT8)(as_read >> 8), hex_str);
			byte_to_hex((UINT8)as_read, hex_str + 2);
			hex_str[4] = '\n';
			hex_str[5] = '\0';
			uart_write_string(UART_0, hex_str);
		}
#endif
		rcc_reload_wdog(0x00);
	}
}

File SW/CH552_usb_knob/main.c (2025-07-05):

#include "CH552.H"
#include "CH552_RCC.h"
#include "CH552_GPIO.h"
#include "CH552_UART.h"
#include "CH552_TIMER.h"
#include "CH552_HID_CC_PAN_MOUSE.h"
#include "CH552_QUADRATURE_ENCODER.h"
#include "pseudo_random.h"

#define BAUD_RATE		125000ul
#define ENABLE_DEBUG	0
#define ENABLE_WIGGLER	1
#define REDUCE_RESOLUTION	1
#define POLL_ENCODER		0
#define DEBOUNCE_SAMPLES	8

//Pins:
// ENCA  = P32
// ENCB  = P33
// ENCSW = P14
// SW1  = P15
// SW2  = P16
// SW3  = P17
// LED1 = P35
// LED2 = P34
// LED3 = P11
// RXD  = P30
// TXD  = P31
// UDP  = P36
// UDM  = P37

#define KNOB_MODE_SCROLL 0
#define KNOB_MODE_PAN 1
#define KNOB_MODE_VOLUME 2

#if ENABLE_DEBUG
char code test_string[] = "Unicorn\n";
char code qenc_str[] = "qenc count: ";
char code pos_str[] = "Knob pos: ";
char code change_str[] = "Pos change: ";
char hex_str[4];
#endif

//Timers
volatile UINT16 mouse_timer = 0;
volatile UINT16 cc_timer = 0;
volatile UINT8 mouse_timeout = 0;
volatile UINT8 cc_timeout = 0;

//Knob state
UINT8 knob_mode = KNOB_MODE_SCROLL;
signed char scroll_speed = 1;
signed char pan_speed = 1;

#if ENABLE_WIGGLER
//Wiggler state
UINT8 wiggler_active = 0;
volatile UINT8 wiggler_update_vel = 0;
volatile UINT8 wiggler_update_pos = 0;
volatile UINT8 wiggler_update_times = 0;
UINT8 time = 0;
UINT16 run_time = 0;
UINT16 stop_time = 0;
signed char x_velocity;
signed char y_velocity;
signed short x_position;
signed short y_position;
signed short prev_x_position;
signed short prev_y_position;
signed char x_delta;
signed char y_delta;
#endif

void on_timer(void)
{
	++mouse_timer;
	++cc_timer;
	
	if(hid_mouse_idle_rate && ((UINT8)(mouse_timer >> 2) >= hid_mouse_idle_rate))
	{
		mouse_timeout = 1;
		mouse_timer = 0;
	}
	
	if(hid_cc_idle_rate && ((UINT8)(cc_timer >> 2) >= hid_cc_idle_rate))
	{
		cc_timeout = 1;
		cc_timer = 0;
	}

#if ENABLE_WIGGLER
	if((knob_mode == KNOB_MODE_PAN) && wiggler_active)
	{
		if(run_time)
		{
			if(time == 0x00)
			{
				wiggler_update_vel = 1;
			}
			if((time & 0x07) == 0x00)
			{
				wiggler_update_pos = 1;
			}
			--run_time;
		}
		else if(stop_time)
		{
			--stop_time;
		}
		else
		{
			wiggler_update_times = 1;
		}
		++time;
	}
#endif
}

#if ENABLE_DEBUG
void byte_to_hex(UINT8 value, char* buff)
{
	const char table[16] = {0x30, 0x31, 0x32, 0x33, 0x34, 0x35, 0x36, 0x37, 0x38, 0x39, 0x41, 0x42, 0x43, 0x44, 0x45, 0x46};
	buff[0] = table[(value >> 4) & 0x0f];
	buff[1] = table[(value) & 0x0f];
	buff[2] = '\0';
}
#endif

int main()
{
	UINT8 knob_sw;
	UINT8 knob_sw_count;
	UINT8 knob_press_event;
	UINT8 knob_release_event;
	
	signed char knob_pos;
	signed char knob_pos_prev;
	signed char knob_pos_change;
	UINT8 knob_inc_event;
	UINT8 knob_dec_event;
	
	rcc_set_clk_freq(RCC_CLK_FREQ_24M);

	gpio_set_mode(GPIO_MODE_INPUT, GPIO_PORT_1, GPIO_PIN_4 | GPIO_PIN_5 | GPIO_PIN_6 | GPIO_PIN_7); // ENCSW, SW123
	gpio_set_mode(GPIO_MODE_INPUT, GPIO_PORT_3, GPIO_PIN_0 | GPIO_PIN_2 | GPIO_PIN_3); // RXD, ENCAB
	gpio_set_mode(GPIO_MODE_PP, GPIO_PORT_3, GPIO_PIN_1 | GPIO_PIN_4 | GPIO_PIN_5); // TXD, LED12
	gpio_set_mode(GPIO_MODE_PP, GPIO_PORT_1, GPIO_PORT_1); // LED3
	
#if ENABLE_DEBUG
	uart0_init(TIMER_1, BAUD_RATE, UART_0_P30_P31);
	timer_init(TIMER_0, NULL);
	timer_set_period(TIMER_0, FREQ_SYS / 1000ul);	//period is 1ms
#endif

	timer_init(TIMER_2, on_timer);
	timer_set_period(TIMER_2, FREQ_SYS / 1000ul);	//period is 1ms
	timer_start(TIMER_2);
	EA = 1;	//enable interupts
	E_DIS = 0;
	
	if(rcc_get_rst_typ() == RCC_RST_TYP_WDOG)
	{
		rcc_delay_ms(500);
	}
	
#if ENABLE_DEBUG	
	//Blink LED once
	gpio_clear_pin(GPIO_PORT_1, GPIO_PIN_1);
	timer_long_delay(TIMER_0, 250);
	gpio_set_pin(GPIO_PORT_1, GPIO_PIN_1);
	timer_long_delay(TIMER_0, 250);
	uart_write_string(UART_0, test_string);
	
	byte_to_hex(RESET_KEEP, hex_str);
	hex_str[2] = '\n';
	hex_str[3] = '\0';
	uart_write_string(UART_0, hex_str);
#endif

	hid_init();
#if POLL_ENCODER
	qenc_init(QENC_MODE_POLLED);
#else
	qenc_init(QENC_MODE_INTERRUPT);
#endif
	pseudo_random_seed(0x1337BEEF);
	rcc_reload_wdog(0x00);
	rcc_set_wdog_rst_en(RCC_WDOG_ENABLED);
	
	gpio_clear_pin(GPIO_PORT_3, GPIO_PIN_5);	//turn on LED1
	knob_sw = gpio_read_pin(GPIO_PORT_1, GPIO_PIN_4);
	knob_sw_count = 0;
	while(TRUE)
	{	
		// Check for mode change and set indicators
		if(!gpio_read_pin(GPIO_PORT_1, GPIO_PIN_5))
		{
			knob_mode = KNOB_MODE_SCROLL;
			gpio_set_pin(GPIO_PORT_1, GPIO_PIN_1);	//turn off LED3
			gpio_set_pin(GPIO_PORT_3, GPIO_PIN_4);	//turn off LED2
			gpio_clear_pin(GPIO_PORT_3, GPIO_PIN_5);	//turn on LED1
		}
		else if(!gpio_read_pin(GPIO_PORT_1, GPIO_PIN_6))
		{
			knob_mode = KNOB_MODE_PAN;
			gpio_set_pin(GPIO_PORT_1, GPIO_PIN_1);	//turn off LED3
			gpio_set_pin(GPIO_PORT_3, GPIO_PIN_5);	//turn off LED1
			gpio_clear_pin(GPIO_PORT_3, GPIO_PIN_4);	//turn on LED2
		}
		else if(!gpio_read_pin(GPIO_PORT_1, GPIO_PIN_7))
		{
			knob_mode = KNOB_MODE_VOLUME;
			gpio_set_pin(GPIO_PORT_3, GPIO_PIN_4 | GPIO_PIN_5);	//turn off LED1 and LED2
			gpio_clear_pin(GPIO_PORT_1, GPIO_PIN_1);	//turn on LED3
		}
		
		// De-bounce the knob state
		if(gpio_read_pin(GPIO_PORT_1, GPIO_PIN_4))
			knob_sw_count += (knob_sw_count <= DEBOUNCE_SAMPLES);
		else
			knob_sw_count -= (knob_sw_count != 0);
		
		knob_press_event = (knob_sw && !knob_sw_count);
		knob_release_event = (!knob_sw && (knob_sw_count == DEBOUNCE_SAMPLES));
		knob_sw = (knob_sw && knob_sw_count) || (knob_sw_count == DEBOUNCE_SAMPLES);
		
#if POLL_ENCODER
		qenc_poll();
#endif
		knob_pos = (signed char)qenc_count;
		knob_pos_change = knob_pos - knob_pos_prev;
#if REDUCE_RESOLUTION
		if((knob_pos_change < -1 ) || (knob_pos_change > 1))
		{
			knob_inc_event = (knob_pos_change > 0);
			knob_dec_event = (knob_pos_change < 0);
			knob_pos_prev = knob_pos;
		}
		else
		{
			knob_inc_event = 0;
			knob_dec_event = 0;
		}
#else
		knob_inc_event = (knob_pos_change > 0);
		knob_dec_event = (knob_pos_change < 0);
		knob_pos_prev = knob_pos;
#endif		
		
#if ENABLE_DEBUG		
		//debug prints
		if(knob_inc_event | knob_dec_event)
		{
			//print qenc_count
			uart_write_string(UART_0, qenc_str);
			byte_to_hex((UINT8)qenc_count, hex_str);
			hex_str[2] = '\n';
			hex_str[3] = '\0';
			uart_write_string(UART_0, hex_str);
			
			//print knob_pos
			uart_write_string(UART_0, pos_str);
			byte_to_hex(knob_pos, hex_str);
			hex_str[2] = '\n';
			hex_str[3] = '\0';
			uart_write_string(UART_0, hex_str);
			
			//print knob_pos_change
			uart_write_string(UART_0, change_str);
			byte_to_hex(knob_pos_change, hex_str);
			hex_str[2] = '\n';
			hex_str[3] = '\0';
			uart_write_string(UART_0, hex_str);
		}
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

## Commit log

2025-06-12 Added HW design files for version 2.0
    [BOM.ods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]
2025-07-04 Created test firmware for mag version
    [BOM.ods]
2025-07-05 Completed preliminary firmware for mag version
    [CH552_HID_CC_MOUSE.obj]
2025-11-13 Added 3D models for mag version, updated releases
    [USB_Knob_Box_Mag v5.f3d, USB_Knob_Cap_Mag.stl, USB_Knob_Mag_Holder v4.f3d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]
2025-11-13 Fixed inverted pan direction (mag)
    [main.c]
